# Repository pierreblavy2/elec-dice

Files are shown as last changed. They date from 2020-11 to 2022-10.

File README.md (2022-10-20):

# elec-dice

# Introduction
This project is an electronic dice that allow to launch 3D4, 3D6, 3D8, 3D10, 1D12, 1D20 or to compute the sum of launched dices. This project was designed to used common and cheap electronic components.

# Components
|quantity|reference|desciption|datasheet|
|---|---|---|---|
|1| 2468|2xAAA battery case|https://www.mouser.fr/datasheet/2/215/468-741064.pdf|
|3|05611AH|7 digit+decimal, common cathode, 0.56 inches|http://www.wayjun.com/Datasheet/Led/Segment%20Digit%20LED%20Display.pdf|
|4|74HC595|8bits shift register,DIP16|https://www.ti.com/lit/ds/symlink/sn74hc595.pdf|
|4|DIP16 support|
|1|ATTiny85|DIP8|https://ww1.microchip.com/downloads/en/DeviceDoc/Atmel-2586-AVR-8-bit-Microcontroller-ATtiny25-ATtiny45-ATtiny85_Datasheet.pdf|
|1|DIP8 support||
|1|5V step up|(1)||
|24|330 ohms|Axial resistor, 1/4W (2)|
|1 |10k ohms|Axial resistor, 1/4W (3)|
|8|1n4007|Diode (4)|https://www.vishay.com/docs/88503/1n4001.pdf|
|8||6x6mm push button|https://www.hdk.co.jp/pdf/eng/e291702.pdf|
|1|ADD3|RPG book, a good dungeon master, friends|

(1) This component is not referenced properly, I've found mine here 
https://www.aliexpress.com/item/32789971588.html but any pin compatible 5V step up will
do the trick. The PCB was designed with extra space arount the 5V step up module, so you can
easily edit it to use an other kind of module. 
The module looks like [this](https://github.com/pierreblavy2/elec-dice/blob/main/doc/5V_OSJK.png?raw=true).

(2) The 330 Ohms resistors are used to protect the 05611AH diodes. You must choose their value according to the kind of led you're using, and the desired brightness. The formula is R=(5-Vf)/If. Vf is the forward voltage of a single LCD segment, If is the segment forward intensity. Note that you must choose a value that's BIGGER than the one you've just computed.

(3) This resistor is used as a pulldown for switches, a wide range of values between 1K to 20K does the job.

(4) These diodes are used to protect the 74hc595 when we press more than one switch. The diode forward voltage drop must be lower than 2V in order to have sufficient voltage on the ATTiny85 input pin.

# Pictures
front_irl
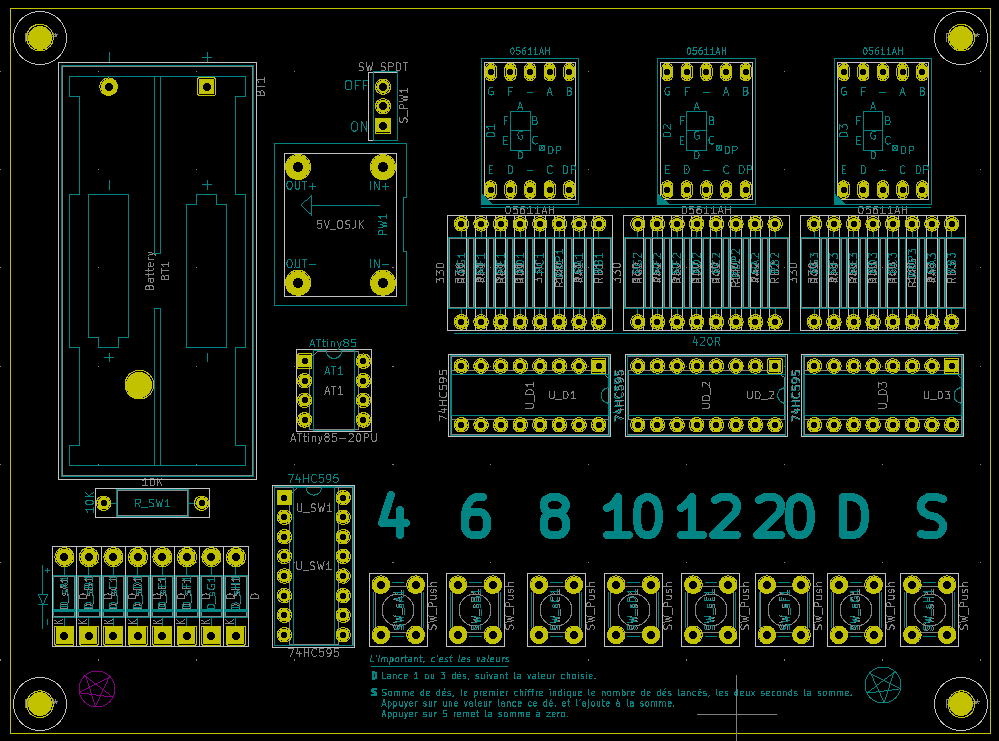
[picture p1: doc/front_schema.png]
front_schema


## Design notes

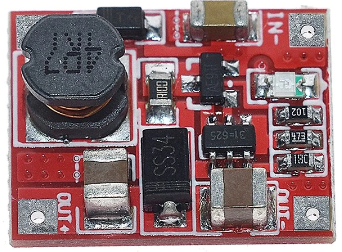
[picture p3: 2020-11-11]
doc/5V_OSJK.png

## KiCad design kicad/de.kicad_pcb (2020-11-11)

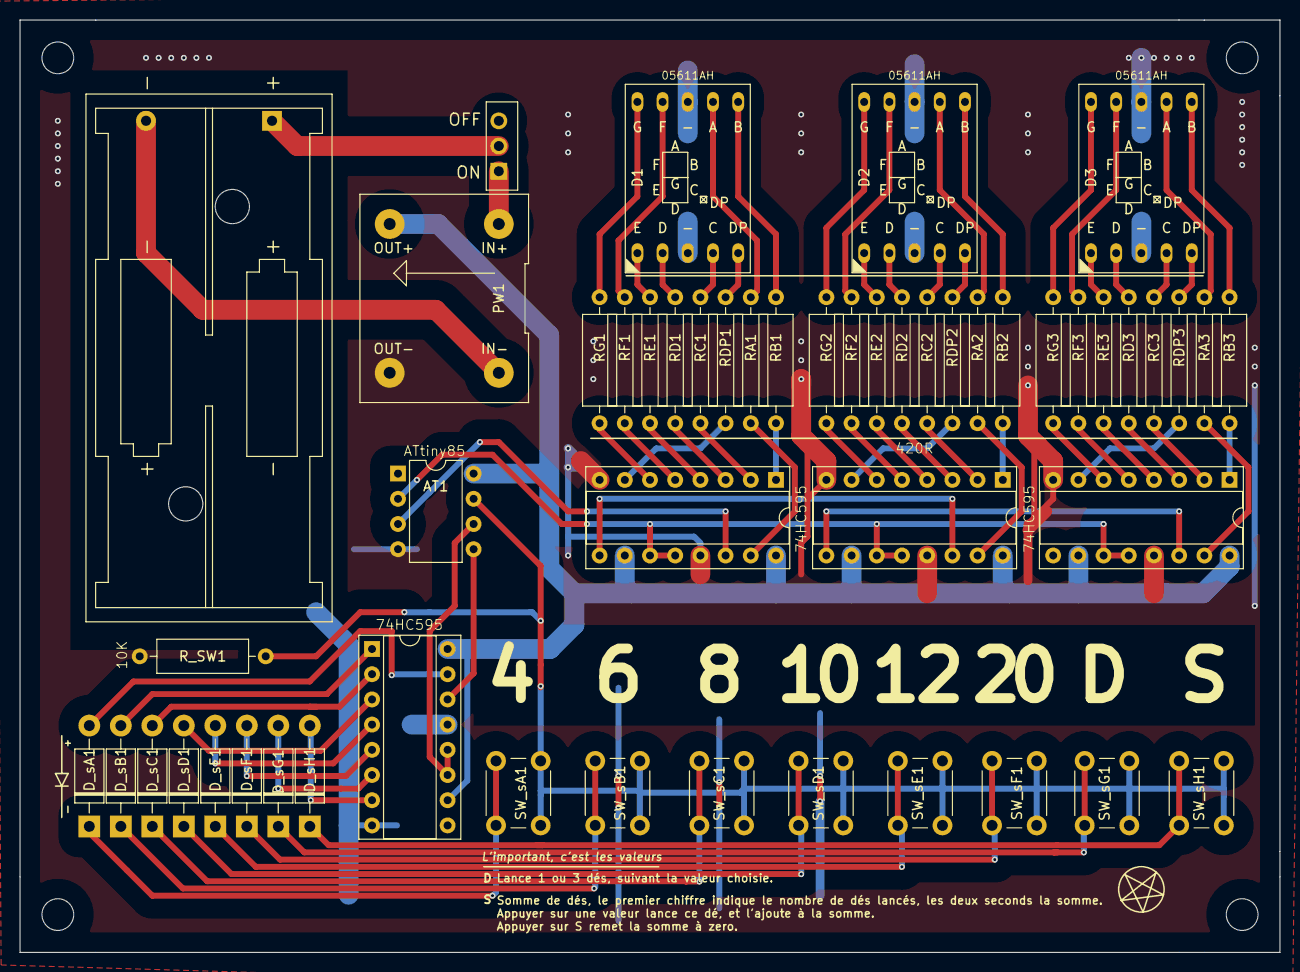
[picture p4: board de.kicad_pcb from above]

Board: 4 copper layers, 127.0 x 94.0 mm, 52 parts (0 on the bottom side), 76 nets.

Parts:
AT1: ATtiny85-20PU; DIP-8_W7.62mm
BT1: Battery; BatteryHolder_Keystone_2468_2xAAA
D1, D2, D3: 05611AH; 7segments-05611AH
D_sA1: D; D_DO-41_SOD81_P10.16mm_Horizontal
D_sB1: D; D_DO-41_SOD81_P10.16mm_Horizontal
D_sC1: D; D_DO-41_SOD81_P10.16mm_Horizontal
D_sD1: D; D_DO-41_SOD81_P10.16mm_Horizontal
D_sE1: D; D_DO-41_SOD81_P10.16mm_Horizontal
D_sF1: D; D_DO-41_SOD81_P10.16mm_Horizontal
D_sG1: D; D_DO-41_SOD81_P10.16mm_Horizontal
D_sH1: D; D_DO-41_SOD81_P10.16mm_Horizontal
PW1: 5V_OSJK
RA1, RA2, RA3: 330; R_Axial_DIN0309_L9.0mm_D3.2mm_P12.70mm_Horizontal
RB1, RB2, RB3: 330; R_Axial_DIN0309_L9.0mm_D3.2mm_P12.70mm_Horizontal
RC1, RC2, RC3: 330; R_Axial_DIN0309_L9.0mm_D3.2mm_P12.70mm_Horizontal
RD1, RD2, RD3: 330; R_Axial_DIN0309_L9.0mm_D3.2mm_P12.70mm_Horizontal
RDP1, RDP2, RDP3: 330; R_Axial_DIN0309_L9.0mm_D3.2mm_P12.70mm_Horizontal
RE1, RE2, RE3: 330; R_Axial_DIN0309_L9.0mm_D3.2mm_P12.70mm_Horizontal
RF1, RF2, RF3: 330; R_Axial_DIN0309_L9.0mm_D3.2mm_P12.70mm_Horizontal
RG1, RG2, RG3: 330; R_Axial_DIN0309_L9.0mm_D3.2mm_P12.70mm_Horizontal
R_SW1: 10K; R_Axial_DIN0309_L9.0mm_D3.2mm_P12.70mm_Horizontal
SW_sA1: SW_Push; SW_PUSH_6mm_H5mm
SW_sB1: SW_Push; SW_PUSH_6mm_H5mm
SW_sC1: SW_Push; SW_PUSH_6mm_H5mm
SW_sD1: SW_Push; SW_PUSH_6mm_H5mm
SW_sE1: SW_Push; SW_PUSH_6mm_H5mm
SW_sF1: SW_Push; SW_PUSH_6mm_H5mm
SW_sG1: SW_Push; SW_PUSH_6mm_H5mm
SW_sH1: SW_Push; SW_PUSH_6mm_H5mm
S_PW1: SW_SPDT; PinHeader_1x03_P2.54mm_Horizontal
UD_2: 74HC595; DIP-16_W7.62mm_Socket
U_D1, U_D3: 74HC595; DIP-16_W7.62mm_Socket
U_SW1: 74HC595; DIP-16_W7.62mm_Socket

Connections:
+5V: AT1.8, PW1.2, UD_2.10, UD_2.16, U_D1.10, U_D1.16, U_D3.10, U_D3.16, U_SW1.10, U_SW1.16
/D_clocks: AT1.2, UD_2.11, UD_2.12, U_D1.11, U_D1.12, U_D3.11, U_D3.12
/D_data: AT1.3, U_D1.14
/Digit 2/data_in: UD_2.14, U_D1.9
/Digit 3/data_in: UD_2.9, U_D3.14
/S_clocks: AT1.6, U_SW1.11, U_SW1.12
/S_data: AT1.5, U_SW1.14
/S_switch: AT1.7, R_SW1.1, SW_sA1.2, SW_sB1.2, SW_sC1.2, SW_sD1.2, SW_sE1.2, SW_sF1.2, SW_sG1.2, SW_sH1.2
GND: AT1.4, D1.3, D1.8, D2.3, D2.8, D3.3, D3.8, PW1.3, R_SW1.2, UD_2.8, UD_2.13, U_D1.8, U_D1.13, U_D3.8, U_D3.13, U_SW1.8, U_SW1.13
unnamed: BT1.1, S_PW1.2
unnamed: BT1.2, PW1.4
unnamed: D1.1, RE1.1
unnamed: D1.2, RD1.1
unnamed: D1.4, RC1.1
unnamed: D1.5, RDP1.1
unnamed: D1.6, RB1.1
unnamed: D1.7, RA1.1
unnamed: D1.9, RF1.1
unnamed: D1.10, RG1.1
unnamed: D2.1, RE2.1
unnamed: D2.2, RD2.1
unnamed: D2.4, RC2.1
unnamed: D2.5, RDP2.1
unnamed: D2.6, RB2.1
unnamed: D2.7, RA2.1
unnamed: D2.9, RF2.1
unnamed: D2.10, RG2.1
unnamed: D3.1, RE3.1
unnamed: D3.2, RD3.1
unnamed: D3.4, RC3.1
unnamed: D3.5, RDP3.1
unnamed: D3.6, RB3.1
unnamed: D3.7, RA3.1
unnamed: D3.9, RF3.1
unnamed: D3.10, RG3.1
unnamed: D_sA1.1, SW_sA1.1
unnamed: D_sA1.2, U_SW1.15
unnamed: D_sB1.1, SW_sB1.1
unnamed: D_sB1.2, U_SW1.1
unnamed: D_sC1.1, SW_sC1.1
unnamed: D_sC1.2, U_SW1.2
unnamed: D_sD1.1, SW_sD1.1
unnamed: D_sD1.2, U_SW1.3
unnamed: D_sE1.1, SW_sE1.1
unnamed: D_sE1.2, U_SW1.4
unnamed: D_sF1.1, SW_sF1.1
unnamed: D_sF1.2, U_SW1.5
unnamed: D_sG1.1, SW_sG1.1
unnamed: D_sG1.2, U_SW1.6
unnamed: D_sH1.1, SW_sH1.1
unnamed: D_sH1.2, U_SW1.7
unnamed: PW1.1, S_PW1.1
unnamed: RA1.2, U_D1.15
unnamed: RA2.2, UD_2.15
unnamed: RA3.2, U_D3.15
unnamed: RB1.2, U_D1.1
unnamed: RB2.2, UD_2.1
unnamed: RB3.2, U_D3.1
unnamed: RC1.2, U_D1.2
unnamed: RC2.2, UD_2.2
unnamed: RC3.2, U_D3.2
unnamed: RD1.2, U_D1.3
unnamed: RD2.2, UD_2.3
unnamed: RD3.2, U_D3.3
unnamed: RDP1.2, U_D1.7
unnamed: RDP2.2, UD_2.7
unnamed: RDP3.2, U_D3.7
unnamed: RE1.2, U_D1.4
unnamed: RE2.2, UD_2.4
unnamed: RE3.2, U_D3.4
unnamed: RF1.2, U_D1.5
unnamed: RF2.2, UD_2.5
unnamed: RF3.2, U_D3.5
unnamed: RG1.2, U_D1.6
unnamed: RG2.2, UD_2.6
unnamed: RG3.2, U_D3.6

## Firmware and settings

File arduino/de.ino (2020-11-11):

//ATTiny85
//processor ATTiny85
//clock internal 16MHz
//programmer Arduino as ISP (not arduinoISP)

//--- wires ---
//Switches
#define S_DATA     ATTINY85_PIN5
#define S_CLOCKS   ATTINY85_PIN6
#define S_SWITCHES ATTINY85_PIN7

//LED
#define D_DATA   ATTINY85_PIN3
#define D_CLOCKS ATTINY85_PIN2


//--- program modes ---
//Modes
#define MODE_DICE true
#define MODE_SUM  false
#include "attiny85.hpp"
#include "display.hpp"
#include "digit_to_byte.hpp"
#include "input.hpp"
#include "dice.hpp"


Display<3>   display(D_DATA , D_CLOCKS) ;
Input<1>     input  (S_DATA , S_CLOCKS , S_SWITCHES);
byte         last_input;
Dice         dice;

bool dice_mode = MODE_DICE;
byte dice_sum;
byte dice_num;




void anime(){
  byte x=0b00000001;
  for(size_t i = 0; i < 8; ++i){
    display.set_byte<0>(x);
    display.set_byte<1>(x);
    display.set_byte<2>(x); 
    display.update();
    delay(50);
    x<<=1;
  }
}



void display_number(byte r){
  display.set_byte<0>(digit_to_byte(r%10,false));
  display.set_byte<1>(digit_to_byte(r/10,false));
  display.set_byte<2>(digit_to_byte(0b00000000,false));
}

void update_dice_sum(byte x){
  if(dice_num<9){
    ++dice_num;
    dice_sum+=x;
  }
  display_number(dice_sum);
  display.set_byte<2>(digit_to_byte(dice_num,true));
}



//input callbacks : One dice per digit
template<int D>
void digit_1_dice_t(){
  anime();
  
  if(dice_mode == MODE_DICE){
      display.set_byte<0>(digit_to_byte(dice(D)%10,true));
      display.set_byte<1>(digit_to_byte(dice(D)%10,true));
      display.set_byte<2>(digit_to_byte(dice(D)%10,true));
  }
  else{
    update_dice_sum(dice(D));
  }
  display.update();
}

void on_d4() {digit_1_dice_t<4>();}
void on_d6() {digit_1_dice_t<6>();}
void on_d8() {digit_1_dice_t<8>();}
void on_d10(){digit_1_dice_t<10>();}


//input callbacks : One dice per 2 digit
template<int D>
void digit_2_dice_t(){
   anime();
   auto r = dice(D);
  
  if(dice_mode == MODE_DICE){
      display.set_byte<0>(digit_to_byte(r%10,false));
      display.set_byte<1>(digit_to_byte((r/10)%10 ,false));
      display.set_byte<2>(0b00000000);
  }
  else{
    update_dice_sum(dice(D));
  }
  display.update();
}


void on_d12() {digit_2_dice_t<12>();}
void on_d20() {digit_2_dice_t<20>();}


void on_sum(){
  dice_mode = MODE_SUM;
  dice_num = 0;
  dice_sum = 0;
  display.set_byte<0>(digit_to_byte(0));
  display.set_byte<1>(digit_to_byte(0));
  display.set_byte<2>(digit_to_byte(0));
  display.update();
}

void on_dice(){
  dice_mode = MODE_DICE;
  display.set_byte<0>(0);
  display.set_byte<1>(0);
  display.set_byte<2>(0);
  display.update();
}



void setup() {
  pinMode(S_DATA    ,OUTPUT);  digitalWrite(S_DATA    ,LOW);
  pinMode(S_CLOCKS  ,OUTPUT);  digitalWrite(S_CLOCKS  ,LOW);
  pinMode(S_SWITCHES,INPUT);   digitalWrite(S_SWITCHES,LOW);
  pinMode(D_CLOCKS  ,OUTPUT);  digitalWrite(D_CLOCKS  ,LOW);
  pinMode(D_DATA    ,OUTPUT);  digitalWrite(D_DATA    ,LOW);
  delay(250);
  
  input.init(); //should flush 0 to switches
  
  //attach callbacks to input
  /*
  input.register_rise(0,on_d4);
  input.register_rise(1,on_d6);
  input.register_rise(2,on_d8);
  input.register_rise(3,on_d10);
  input.register_rise(4,on_d12);
  input.register_rise(5,on_d20);
  input.register_rise(6,on_dice_sum);
  input.register_rise(7,on_dice);
  */

  display.set_byte<0>(0b10101010);
  display.set_byte<1>(0b01010101);
  display.set_byte<2>(0b11001100);
  display.update_force();
  delay(700);

  input.scan();
  last_input=input.data[0];
  
}



void loop() {
  byte mask;


  
  //track changes
  input.scan();
  mask = 0b10000000;
  
  for(size_t i=0; i < 8; ++i){
    byte old_bit = mask & last_input;
    byte new_bit = mask & input.data[0];
    if(old_bit!=new_bit){
    bool is_rise = (old_bit==0);
    if(is_rise){
      switch(i){
        case 0 : {on_d4();   break;}
        case 1 : {on_d6();   break;}
        case 2 : {on_d8();   break;}
        case 3 : {on_d10();  break;}
        case 4 : {on_d12();  break;}
        case 5 : {on_d20();  break;}
        case 6 : {on_dice(); break;}
        case 7 : {on_sum();  break;}
      }
    }
    }
    mask>>=1;
  }
  last_input=input.data[0];

  
  display.update();
}

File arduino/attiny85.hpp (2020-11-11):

#ifndef ATTINY85_HPP_PINS_
#define ATTINY85_HPP_PINS_


// !RESET A0 1    8 VCC +5V
//        A3~2    7 A1
//        A2~3    6~D1
//       GND 4    5~D0

// 1 reset when connected to ground
// ~ PWM
// Ax : analog input



//      ATTINY85_PIN1 RESET (5)
#define ATTINY85_PIN2 3
#define ATTINY85_PIN3 4
//        TINY85_PIN4 GND
#define ATTINY85_PIN5 0
#define ATTINY85_PIN6 1
#define ATTINY85_PIN7 2
//        TINY85_PIN8 +5V


#endif
